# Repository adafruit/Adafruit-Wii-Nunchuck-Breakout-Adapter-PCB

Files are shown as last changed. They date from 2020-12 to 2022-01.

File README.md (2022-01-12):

## Adafruit Wii Nunchuck Breakout Adapter PCB

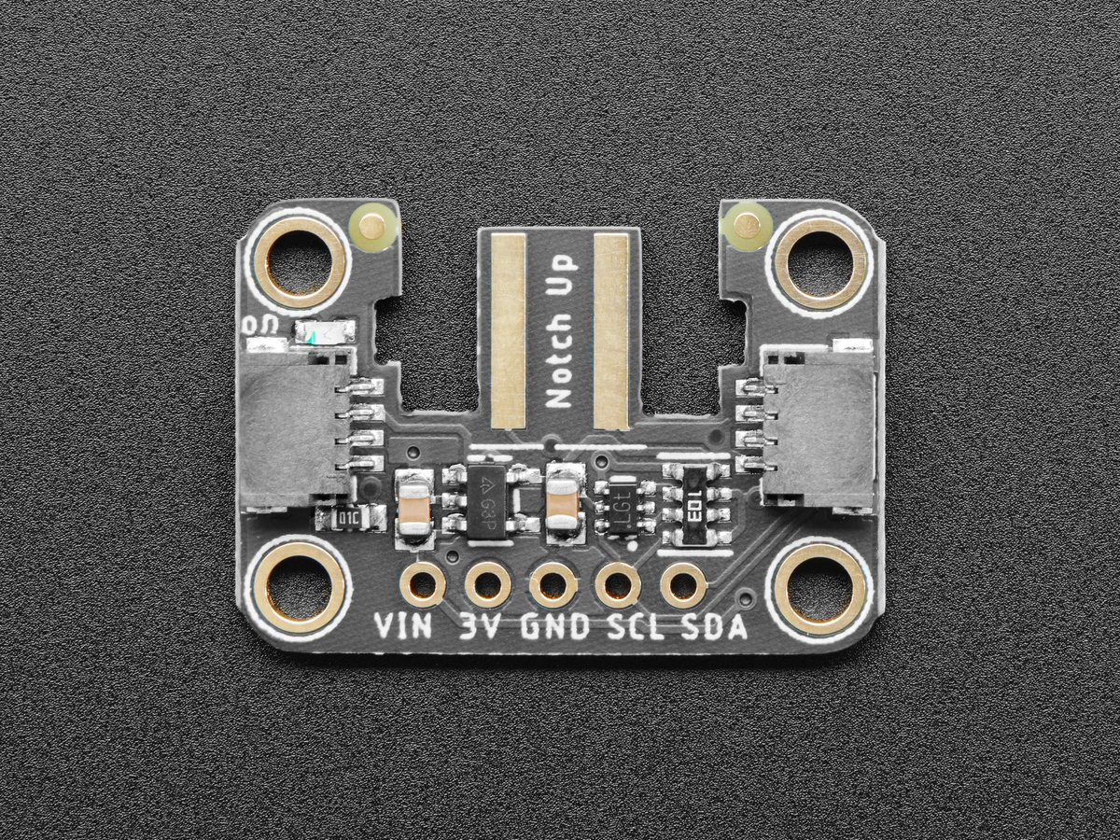
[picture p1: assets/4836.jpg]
<a href="http://www.adafruit.com/products/4836"><br/>
Click here to purchase one from the Adafruit shop</a>

PCB files for the Adafruit Wii Nunchuck Breakout Adapter.

Format is EagleCAD schematic and board layout
* https://www.adafruit.com/product/4836

### Description

Dig out that old Wii controller and use it as a sleek controller for your next robot if you like. The Adafruit Adafruit Wii Nunchuck Breakout Adapter fits snugly into the Wii connector, and performs the level shifting and power regulation needed to use the controller with any microcontroller or microcomputer.

The Wii controllers use a standard I2C interface, and there's existing code for both Arduino and CircuitPython/Python for quick integration with an Arduino UNO, Feather, or even a Raspberry Pi. We like to use these with the Wii Nunchuck, as you can get an X-Y joystick, two buttons and an accelerometer all in one hand-held package. All data is transmitted over I2C address 0x52, and the address can not be changed.

We use extra thicc 2.0mm PCBs for this breakout, and made cut-outs for the grabber-notches, so that the controller connection is snug, and wont rattle or come loose!

To make using it as easy as possible, we’ve created this breakout in Stemma QT form factor. You can either use a breadboard or the SparkFun qwiic compatible STEMMA QT connectors, and compatibility with 5V voltage levels as commonly found on Arduinos, as well as 3.3V logic used by many other boards like the Raspberry Pi or our Feathers. QT Cable is not included, but we have a variety in the shop for quick plug-and-play support.

Doesn't come with the Wii Nunchuck controller, that's sold separately (or just look in that plastic bin in your parent's attic next time you visit).

### License

Adafruit invests time and resources providing this open source design, please support Adafruit and open-source hardware by purchasing products from [Adafruit](https://www.adafruit.com)!

Designed by Limor Fried/Ladyada for Adafruit Industries.

Creative Commons Attribution/Share-Alike, all text above must be included in any redistribution.
See license.txt for additional details.

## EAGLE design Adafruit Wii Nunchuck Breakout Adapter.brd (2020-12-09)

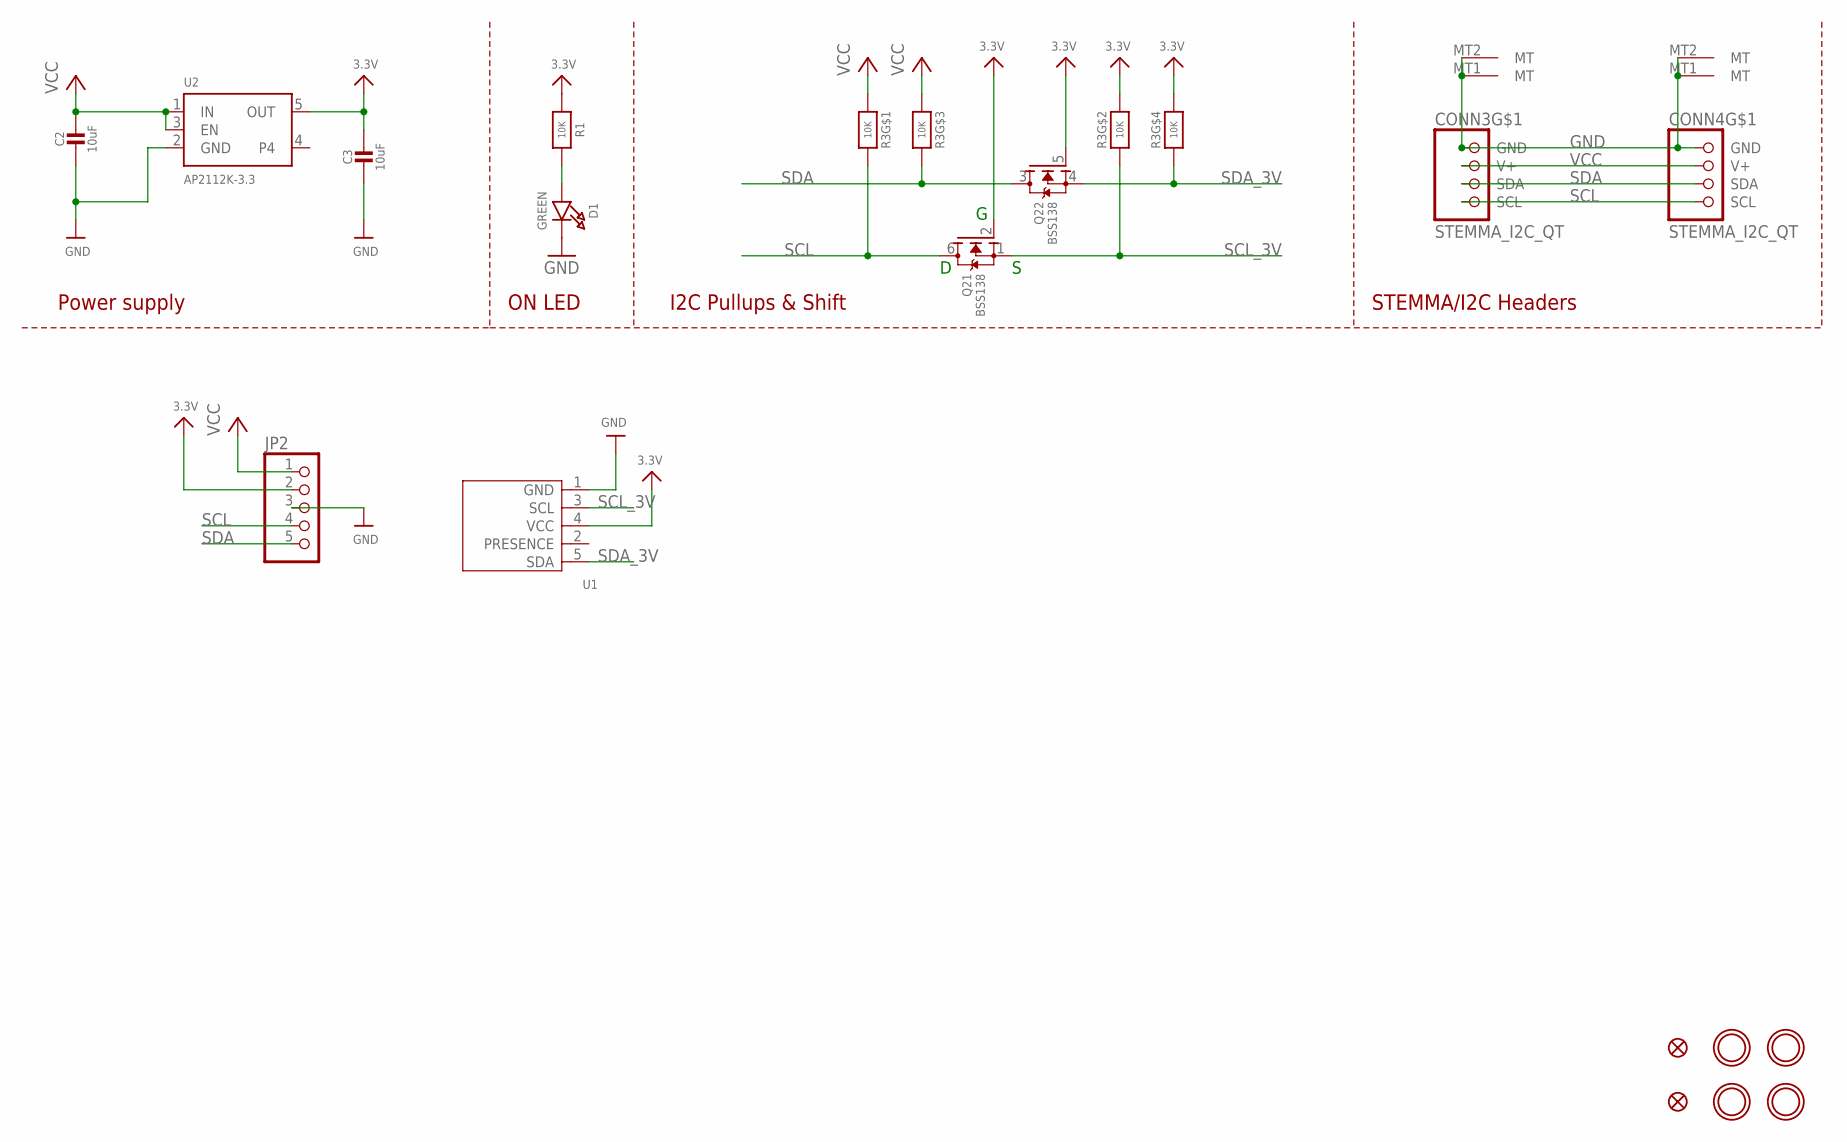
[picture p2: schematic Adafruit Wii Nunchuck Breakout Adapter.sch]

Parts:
C2, C3: 10uF; 0805-NO
CONN3, CONN4: STEMMA_I2C_QT; JST_SH4
D1: GREEN; CHIPLED_0603_NOOUTLINE
FID3, FID4: FIDUCIAL_1MM
JP2: HEADER-1X570MIL; 1X05_ROUND_70
Q2: BSS138; SOT363
R1: 10K; 0603-NO
R3: 10K; RESPACK_4X0603
U1: WIICHUCK
U2: AP2112K-3.3; SOT23-5
U$1, U$17, U$19, U$21: MOUNTINGHOLE2.5; MOUNTINGHOLE_2.5_PLATED

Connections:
3.3V: C3.1, JP2.2, Q2.2 (G), Q2.5 (G), R1.1, R3.2 (1), R3.4 (1), U1.4 (VCC), U2.5 (OUT)
GND: C2.2, C3.2, CONN3.1 (GND), CONN3.MT1 (MT), CONN3.MT2 (MT), CONN4.1 (GND), CONN4.MT1 (MT), CONN4.MT2 (MT), D1.C, JP2.3, U1.1 (GND), U2.2 (GND)
unnamed: D1.A, R1.2
SCL: CONN3.4 (SCL), CONN4.4 (SCL), JP2.4, Q2.6 (D), R3.8 (2)
SCL_3V: Q2.1 (S), R3.7 (2), U1.3 (SCL)
SDA: CONN3.3 (SDA), CONN4.3 (SDA), JP2.5, Q2.3 (D), R3.6 (2)
SDA_3V: Q2.4 (S), R3.5 (2), U1.5 (SDA)
VCC: C2.1, CONN3.2 (V+), CONN4.2 (V+), JP2.1, R3.1, R3.3 (1), U2.1 (IN), U2.3 (EN)

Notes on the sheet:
I2C Pullups & Shift
STEMMA/I2C Headers
ON LED
Power supply

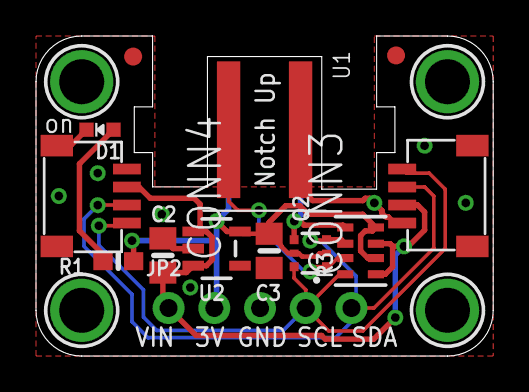
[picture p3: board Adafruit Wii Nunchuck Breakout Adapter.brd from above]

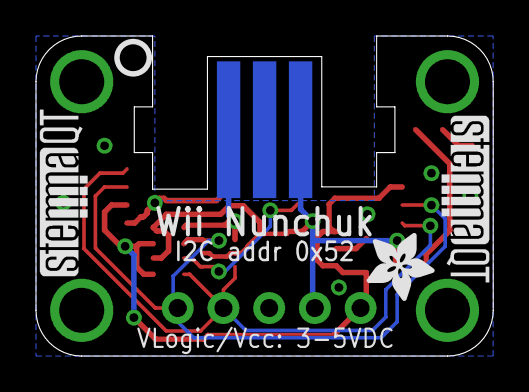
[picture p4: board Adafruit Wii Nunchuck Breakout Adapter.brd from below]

Board: 2 copper layers, 25.4 x 17.8 mm, 21 parts (4 on the bottom side), 8 nets.

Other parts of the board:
U$22: ADAFRUIT_3.5MM
U$25: PCBFEAT-REV-040
U$30, U$31: STEMMAQT

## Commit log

2020-12-09 adding board files.
    [Adafruit Wii Nunchuck Breakout Adapter.brd, Adafruit Wii Nunchuck Breakout Adapter.sch]
2022-01-12 Changed typo'd I2C address from 0x53 to 0x52

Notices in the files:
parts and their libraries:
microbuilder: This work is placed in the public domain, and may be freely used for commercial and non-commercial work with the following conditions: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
